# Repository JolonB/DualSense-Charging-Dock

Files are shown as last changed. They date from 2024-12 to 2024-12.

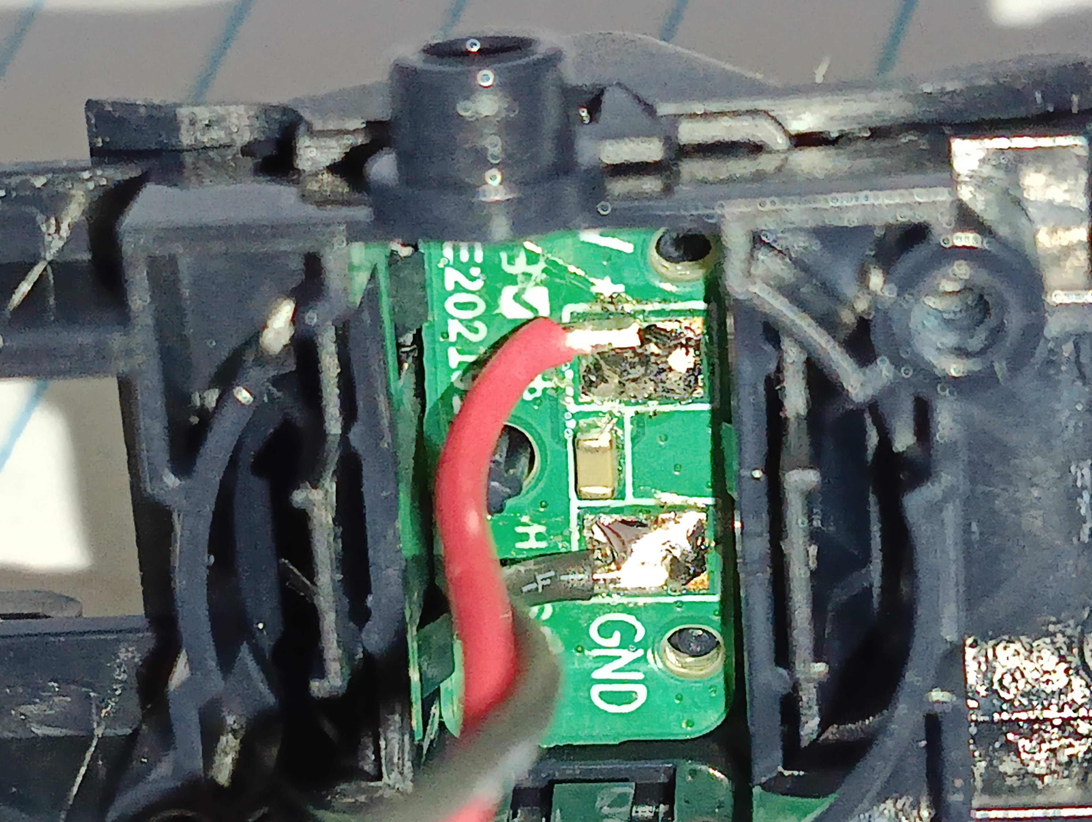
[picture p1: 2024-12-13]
assets/images/h.jpg

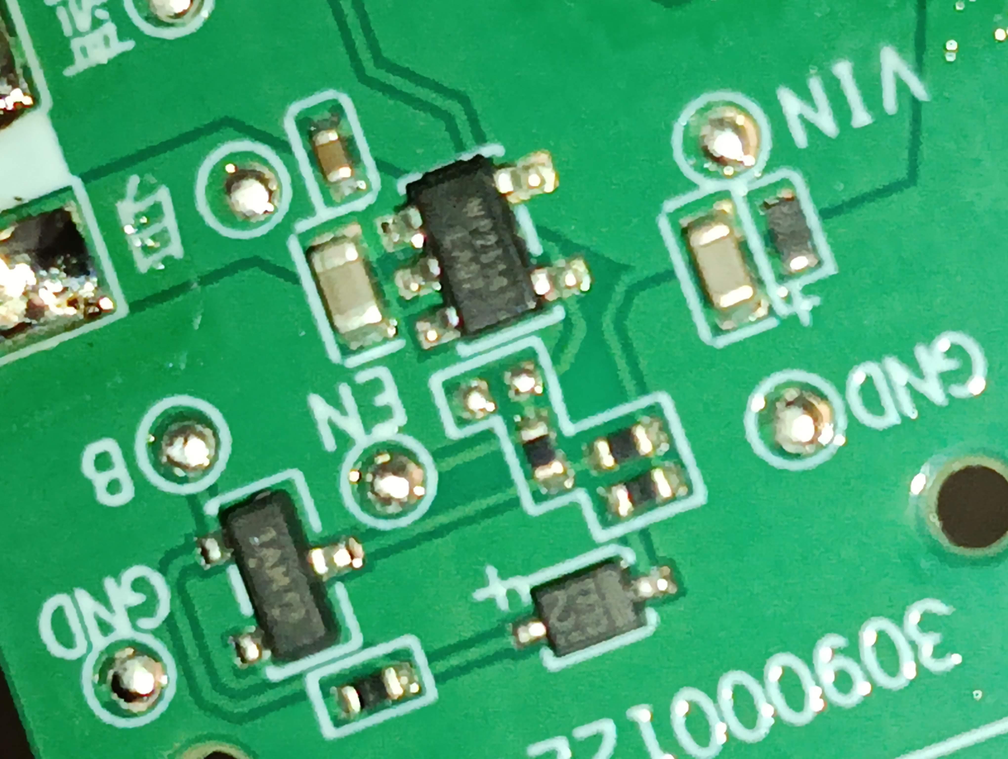
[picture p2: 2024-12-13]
assets/images/f.jpg

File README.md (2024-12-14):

# DualSense Charging Dock

In the interest of increased repairability, I've compiled some useful information about the DualSense charging dock.

This includes schematics, pictures, and teardown instructions.

## Teardown

I found the following teardown guides very useful.
Rather than replicating instructions, I'll point you to these resources:

* [Video](https://www.youtube.com/watch?v=xvCFaVB1jn4)
* [Text](https://www.ifixit.com/Answers/View/690457/Dualsense+Charging+Station+Tear+Down+Guide)

Personally, I found the video guide to be more useful.

## Pictures

Images can be found in `assets/images`.

## Schematics

Schematics can be found in the `charging-dock` directory.
These were created using KiCad 8.

The part numbers may not be exact as some of them are based entirely off the two letters written on top.
In most cases, I was unable to get the values of resistors and capacitors, and it is difficult to work out what they should be without knowing the specifications of the other components.
The components with markings are described below:

* WP25141: Current-limited switch. Has enable input to allow power to pass from IN to OUT. Fault detection pin is not connected. I believe this is used for cutting power to the controllers, however, in my simulations, it only works in an undervoltage situation, so won't protect against high-voltage inputs.
* 1AM: [A 3-terminal device, very likely an NPN transistor](https://smd.yooneed.one/code3141.html#code31414d). This is used for enabling the WP25141 switches. When the BJT is open, the output is enabled.
* E2: [Some type of diode, likely a Zener](https://smd.yooneed.one/code4532.html#code4532). I think this is used to only allow the BJT to turn close when the voltage exceeds some threshold. This prevents power reaching the controller in an over-voltage condition.
* GD: [Some type of diode, likely a Zener](https://smd.yooneed.one/code4744.html#code4744). I believe this is used for ESD protection on the input, so it just handles large voltage spikes. I suspect it could be KDZ36B.

Datasheets for the mentioned components can be found in `assets/datasheets`.

The barrel jack footprint is also much bigger than it should be; I just used the closest footprint built in to KiCad.
The charging pin PCB is also not very accurate because I couldn't take it out to measure.

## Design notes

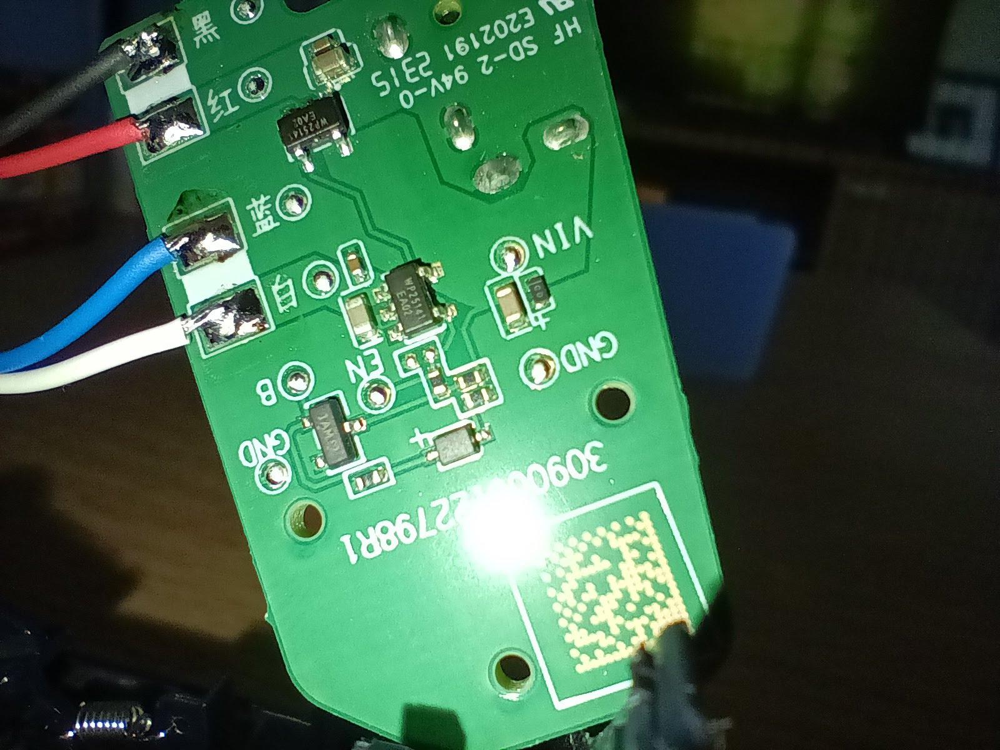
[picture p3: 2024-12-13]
assets/images/b.jpg

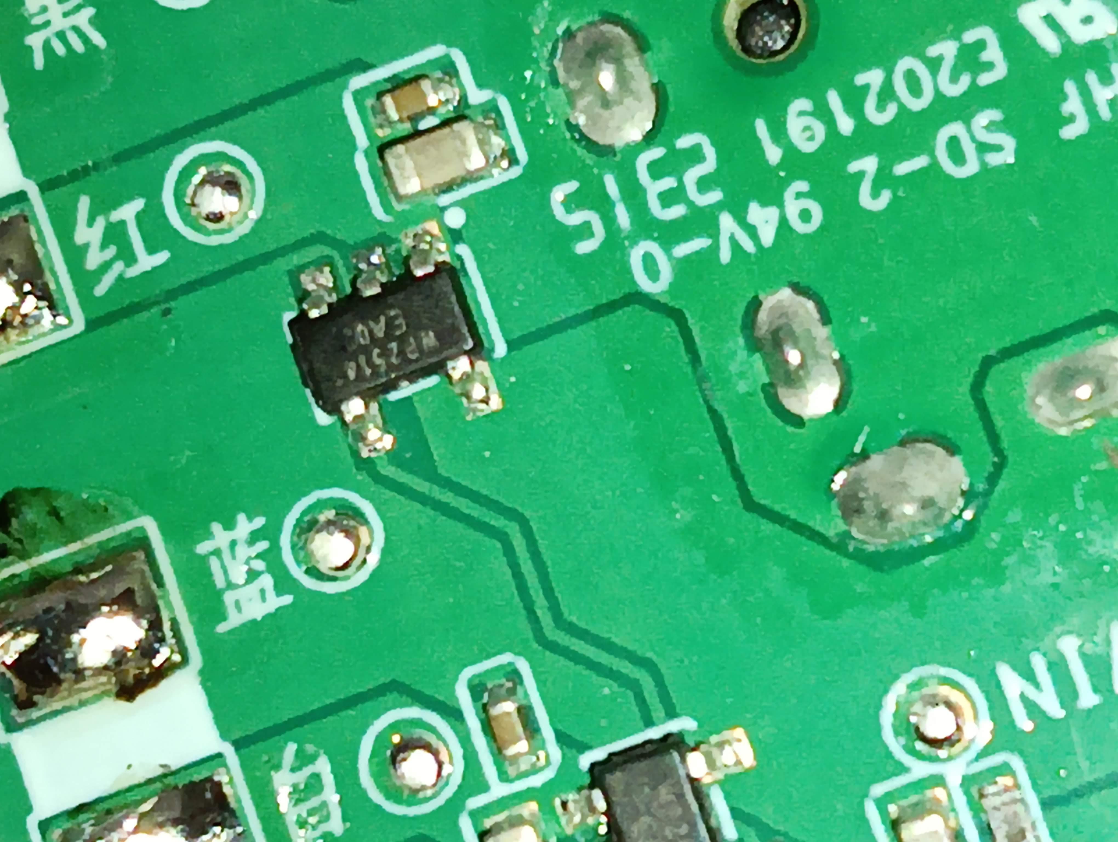
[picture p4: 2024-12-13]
assets/images/e.jpg

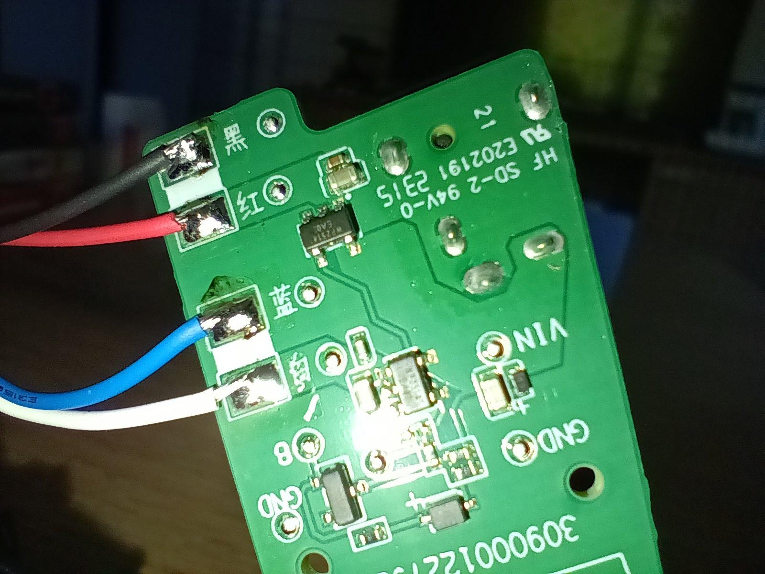
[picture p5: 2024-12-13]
assets/images/a.jpg

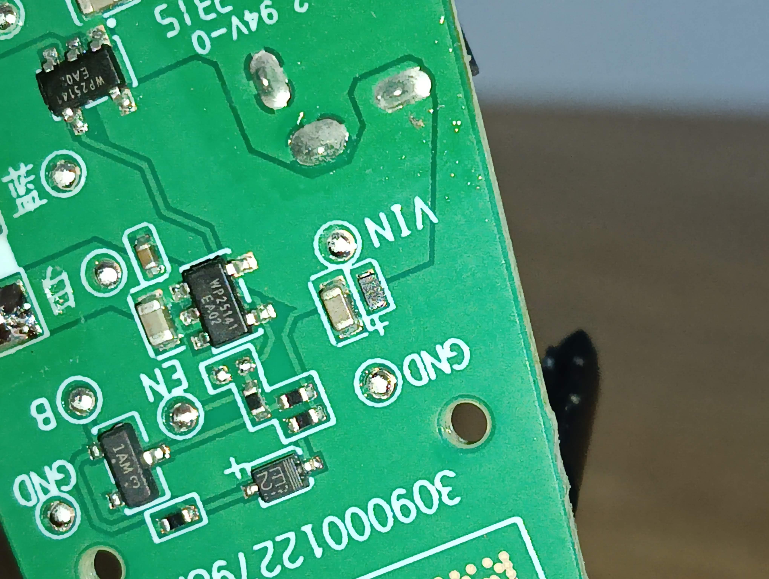
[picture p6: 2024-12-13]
assets/images/d.jpg

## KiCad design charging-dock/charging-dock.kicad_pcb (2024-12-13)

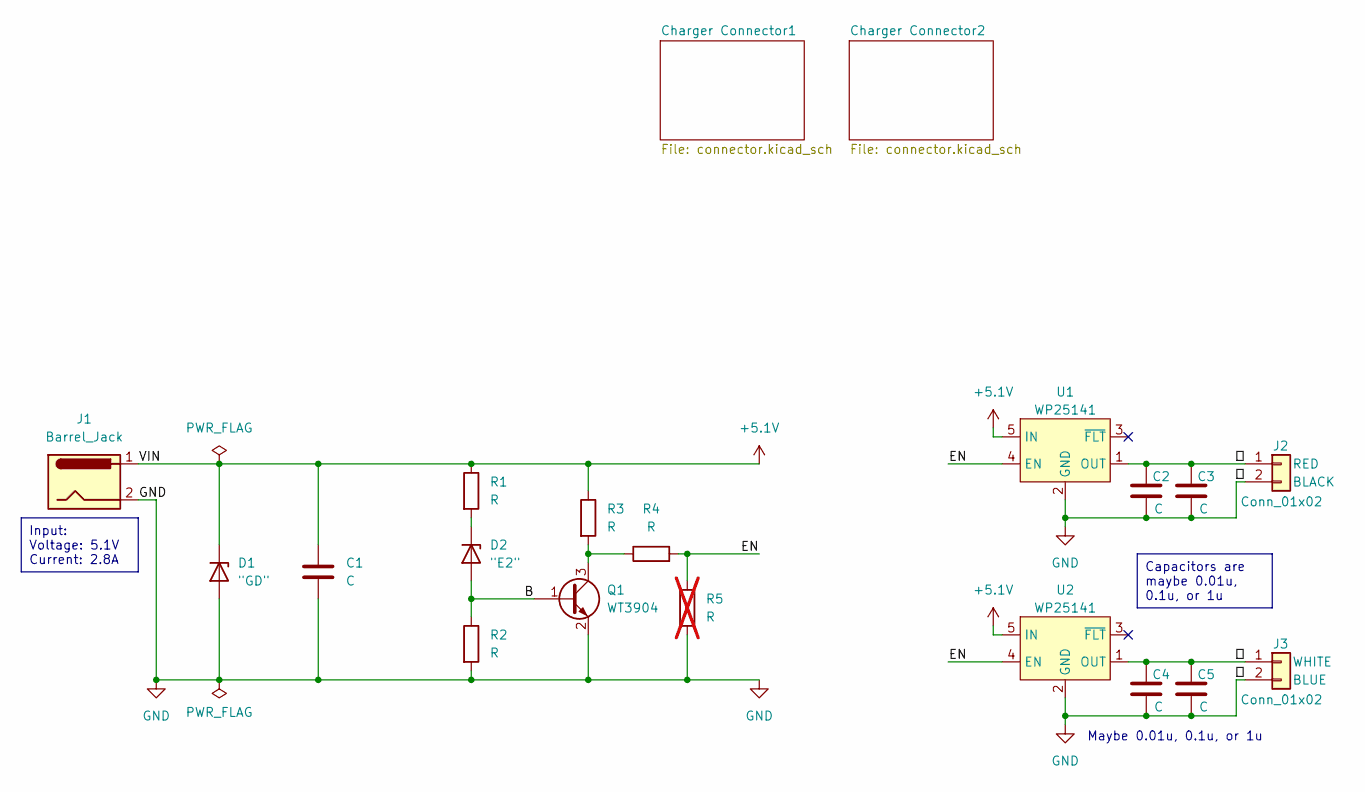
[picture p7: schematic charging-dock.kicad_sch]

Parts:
C1, C2, C4: C; C_0603_1608Metric
C3, C5: C; C_0402_1005Metric
D1: "GD"; D_SOD-323F
D2: "E2"; D_SOD-323
J1: Barrel_Jack; BarrelJack_CUI_PJ-079BH_Horizontal
J2, J3: Conn_01x02; Power Pads
Q1: WT3904; SOT-23
R1, R2, R3, R4: R; R_0402_1005Metric
R5: R; R_0402_1005Metric; not fitted
U1, U2: WP25141; SOT-23-5

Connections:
+5.1V: C1.2, D1.1 (K), J1.1, R1.1, R3.1, U1.5 (IN), U2.5 (IN)
/B: D2.2 (A), Q1.1 (B), R2.1
/EN: R4.2, R5.1, U1.4 (EN), U2.4 (EN)
/白: C4.1, C5.1, J3.1, U2.1 (OUT)
/紅: C2.1, C3.1, J2.1, U1.1 (OUT)
GND: C1.1, C2.2, C3.2, C4.2, C5.2, D1.2 (A), J1.2, J1.3, J1.SH, J2.2, J3.2, Q1.2 (E), R2.2, R5.2, U1.2 (GND), U2.2 (GND)
unnamed: D2.1 (K), R1.2
unnamed: Q1.3 (C), R3.2, R4.1

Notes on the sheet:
Capacitors are maybe 0.01u, 0.1u, or 1u
Input: Voltage: 5.1V Current: 2.8A
Maybe 0.01u, 0.1u, or 1u

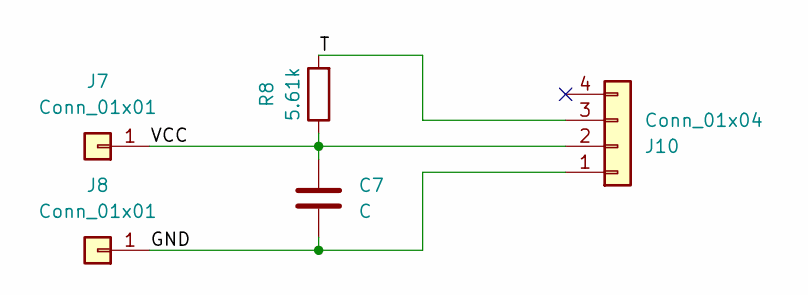
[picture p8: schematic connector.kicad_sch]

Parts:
C7: C; C_0402_1005Metric
J7, J8: Conn_01x01; SolderWirePad_1x01_SMD_1x2mm
J10: Conn_01x04; SolderWire-0.1sqmm_1x04_P3.6mm_D0.4mm_OD1mm_Relief
R8: 5.61k; R_0402_1005Metric

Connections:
/Charger Connector1/GND: C7.2, J8.1, J10.1
/Charger Connector1/T: J10.3, R8.2
/Charger Connector1/VCC: C7.1, J7.1, J10.2, R8.1

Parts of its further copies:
C6: C; C_0402_1005Metric
J4, J5: Conn_01x01; SolderWirePad_1x01_SMD_1x2mm
J9: Conn_01x04; SolderWire-0.1sqmm_1x04_P3.6mm_D0.4mm_OD1mm_Relief
R7: 5.61k; R_0402_1005Metric

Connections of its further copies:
/Charger Connector2/GND: C6.2, J5.1, J9.1
/Charger Connector2/T: J9.3, R7.2
/Charger Connector2/VCC: C6.1, J4.1, J9.2, R7.1

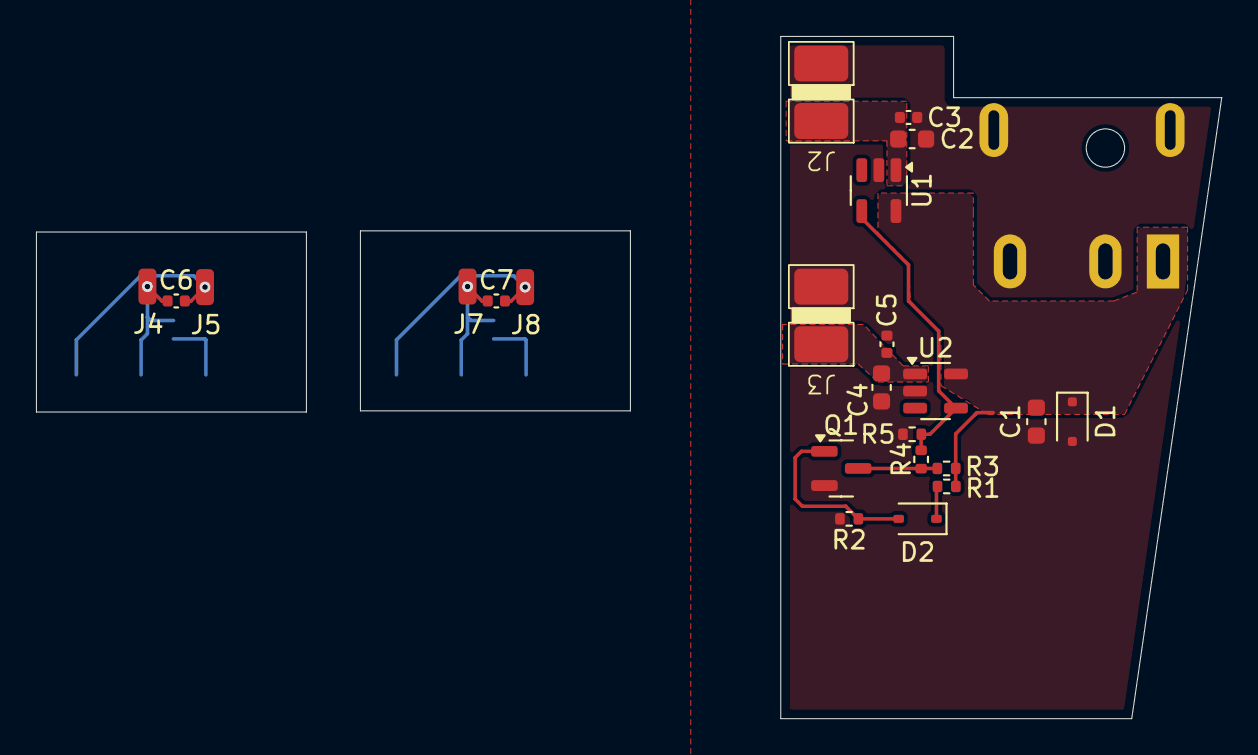
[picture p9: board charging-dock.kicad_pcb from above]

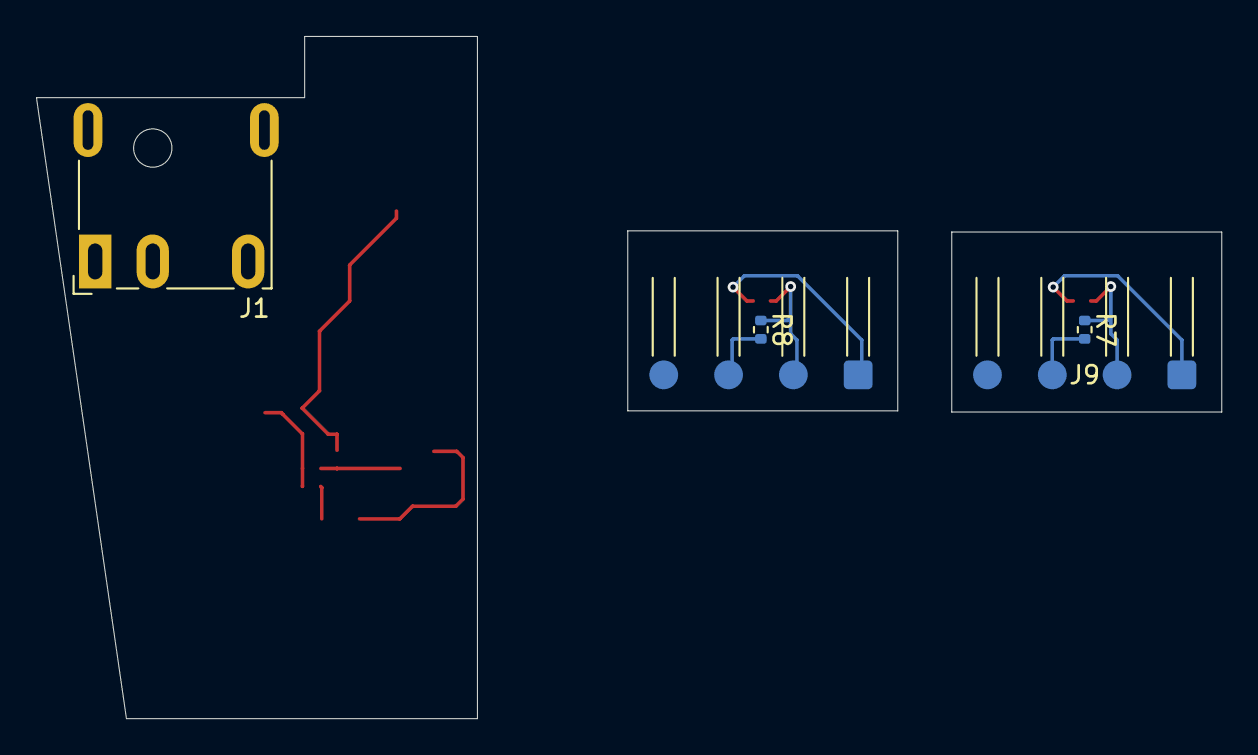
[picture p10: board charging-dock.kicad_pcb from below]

Board: 2 copper layers, 65.8 x 37.9 mm, 28 parts (5 on the bottom side), 14 nets.
